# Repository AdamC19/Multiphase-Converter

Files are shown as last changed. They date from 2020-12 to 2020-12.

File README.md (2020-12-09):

# Multiphase Forward Converter
This repo contains the hardware source files for my digitally controlled multiphase isolated 1000W forward
converter. (firmware source code repo is
[here](https://github.com/AdamC19/Multiphase-Converter-FW).) This is a work in progress

## Update December 2020
First prototype has been built up, initial testing is promising! See more [here](http://acordingley.us/multiphase-converter/).

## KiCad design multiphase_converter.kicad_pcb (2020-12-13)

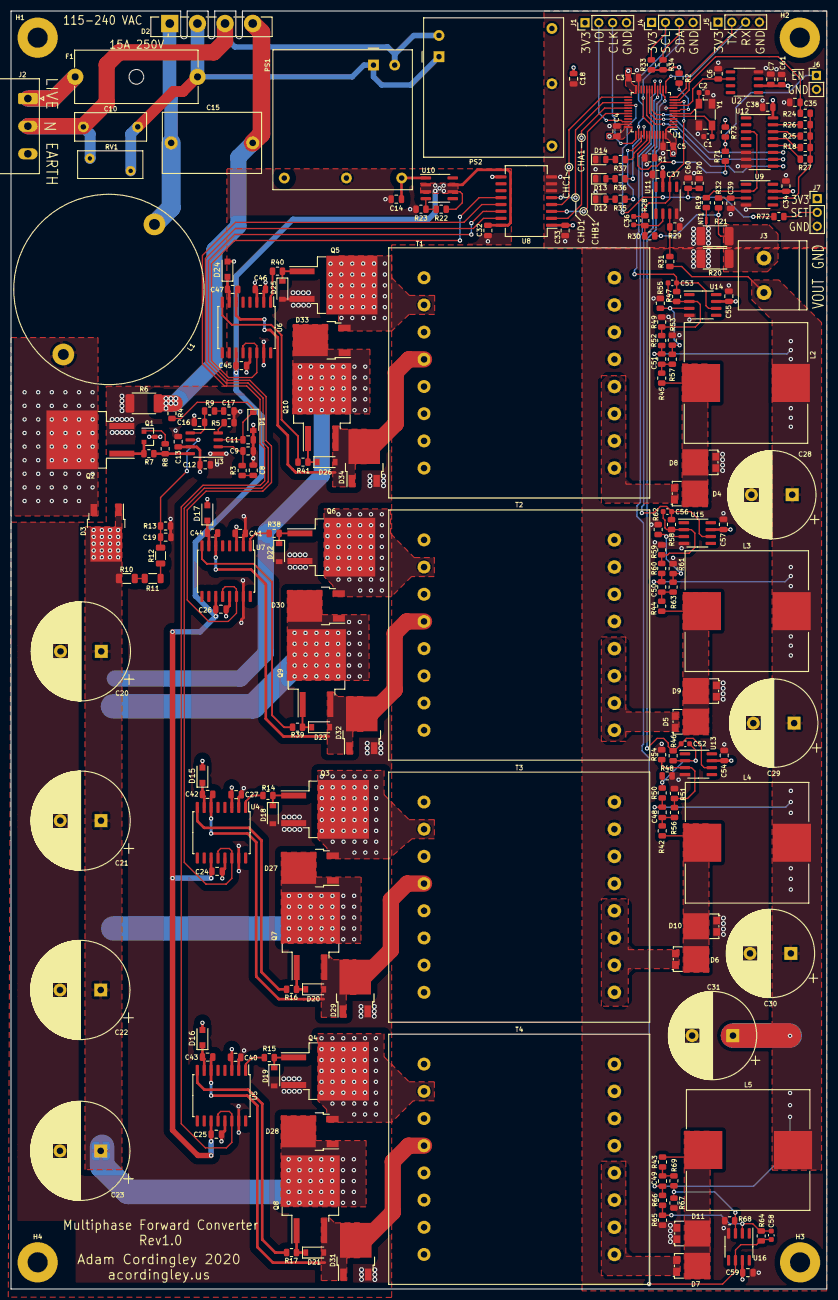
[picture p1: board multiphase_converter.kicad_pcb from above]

Board: 4 copper layers, 150.0 x 235.0 mm, 220 parts (0 on the bottom side), 123 nets.

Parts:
C1, C2: 18p; C_0603_1608Metric
C3, C4, C5, C7, C13, C24, C25, C26, C27, C32, C33, C34, C35, C37, C38, C40, C41, C42, C43, C44, C45, C46, C47, C48, C49, C50, C51, C54, C55, C57, C59, C60: 0.1u; C_0805_2012Metric
C6, C12, C61: 1u; C_0805_2012Metric
C8: DNP; C_0805_2012Metric
C9, C11: 1200p; C_0805_2012Metric
C10: 4700p; C_Rect_L13.0mm_W5.0mm_P10.00mm_FKS3_FKP3_MKS4
C14, C18: 10u; C_0805_2012Metric
C15: R463I347050N0M; C_Rect_L18.0mm_W11.0mm_P15.00mm_FKS3_FKP3
C16: 2.2u; C_0805_2012Metric
C17: 22u; C_0805_2012Metric
C19: 680p; C_0805_2012Metric
C20, C21, C22, C23: 220u; CP_Radial_D18.0mm_P7.50mm
C28, C29, C30, C31: UCS2C221MHD1TN; CP_Radial_D16.0mm_P7.50mm
C36, C52, C53, C56, C58: 6.8p; C_0603_1608Metric
C39: 0.01u; C_0805_2012Metric
D1: 1N4148W; D_SOD-123
D2: GBU2510-G; Diode_Bridge_Vishay_GBU
D3, D27, D28, D29, D30, D31, D32, D33, D34: C3D04060E; TO-252-2
D4, D5, D6, D7, D8, D9, D10, D11: FSV15100V; TO-277A
D12, D13, D14: LED; LED_0805_2012Metric
D15, D16, D17, D24: S1MFL; D_SOD-123F
D18, D19, D20, D21, D22, D23, D25, D26: 15V; D_SOD-123
F1: 0031.8201; Fuseholder_Cylinder-5x20mm_Schurter_0031_8201_Horizontal_Op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
H1, H2, H3, H4: #6; MountingHole_3.7mm_Pad
J1, J4, J5: Conn_01x04_Male; PinHeader_1x04_P2.54mm_Vertical
J2: 1923872; PhoenixContact_MSTBA_2,5_3-G-5,08_1x03_P5.08mm_Horizontal
J3: 1714955; Phoenix_MKDS_5_2-6,35
J6: Conn_01x02_Male; PinHeader_1x02_P2.54mm_Vertical
J7: Conn_01x03_Male; PinHeader_1x03_P2.54mm_Vertical
L1: 120u; Bourns_1140_121K
L2, L3, L4, L5: 74435583300; L_Wuerth_HCI-2212
NT1: Net-Tie_2; NetTie-2_SMD_Pad0.5mm
PS1: RAC05-12SK; Converter_ACDC_RECOM_RAC05-xxSK_THT
PS2: RAC05-3.3SK; Converter_ACDC_RECOM_RAC05-xxSK_THT
Q1: BC807; SOT-23
Q2: IPB60R060P7ATMA1; TO-263-2
Q3, Q4, Q5, Q6, Q7, Q8, Q9, Q10: Q_NMOS_GDS; TO-263-2
R1, R2, R8, R19, R24, R32: 1k; R_0805_2012Metric
R3: DNP; R_0805_2012Metric
R4: 220; R_0805_2012Metric
R5: 13.7k; R_0805_2012Metric
R6: 0.015; R_2512_Power
R7, R14, R15, R16, R17, R38, R39, R40, R41: 3.3; R_0805_2012Metric
R9: 4.7k; R_0805_2012Metric
R10, R11, R12: 330k; R_1206_3216Metric
R13: 14.3k; R_0805_2012Metric
R18: 1.5M; R_0805_2012Metric
R20, R21: 0.003; R_2512_Power
R22: 240; R_0805_2012Metric
R23: 720; R_0805_2012Metric
R25, R30, R31, R50, R52, R56, R57, R60, R63, R66, R69, R70: 200k; R_0805_2012Metric
R26, R71, R72: 100k; R_0805_2012Metric
R27: 50k; R_0805_2012Metric
R28, R29, R48, R49, R51, R53, R59, R61, R65, R67, R73: 10k; R_0805_2012Metric
R33, R34: 2.2k; R_0805_2012Metric
R35, R36, R37: 330; R_0805_2012Metric
R42, R43, R44, R45: 25k; R_0805_2012Metric
R46, R47, R54, R55, R58, R62, R64, R68: 2.4M; R_0805_2012Metric
RV1: MOV-10D391KTR; RV_Disc_D12mm_W5.1mm_P7.5mm
T1, T2, T3, T4: Wurth_760895751
U1: STM32F334C8Tx; LQFP-48_7x7mm_P0.5mm
U2: ADR45xx; SO-8_3.9x4.9mm_P1.27mm
U3: UCC28180; SO-8_3.9x4.9mm_P1.27mm
U4, U5, U6, U7: IR2113S; SOIC-16W_7.5x10.3mm_P1.27mm
U8: ADuM260N; SOIC-16W_7.5x12.8mm_P1.27mm
U9: AD8551; SOIC-8_3.9x4.9mm_P1.27mm
U10: LM317L_SO8; SOIC-8_3.9x4.9mm_P1.27mm
U11, U13, U14, U15, U16: TSV911IDT; SOIC-8_3.9x4.9mm_P1.27mm
U12: 74HC4051; SOIC-16_3.9x9.9mm_P1.27mm
Y1: ABM3B-16.000MHZ-B2-T; Crystal_SMD_Abracon_ABM3B-4Pin_5.0x3.2mm

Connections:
+3V3: C3.2, C4.2, C5.2, C7.1, C18.1, C33.1, C34.1, C37.1, C38.1, C54.1, C55.1, C57.1, C59.1, C61.2, J1.1, J4.1, J5.1, J7.1, PS2.5, R2.1, R33.1, R34.1, R73.1, U1.1, U1.24, U1.36, U1.48, U2.2, U8.1, U9.7, U11.7, U12.16, U13.7, U14.7, U15.7, U16.7
+5VA: C24.1, C25.1, C26.1, C32.1, C45.1, R22.1, U4.11, U5.11, U6.11, U7.11, U8.16, U10.2, U10.3, U10.6, U10.7
+12V: C12.2, C13.2, C14.1, C27.2, C40.2, C41.2, C46.2, D15.2, D16.2, D17.2, D24.2, PS1.5, U3.7, U4.3, U5.3, U6.3, U7.3, U10.1
/Control/ENABLE: R71.2, U1.42
/Control/RX: J5.3, U1.13
/Control/SCL: J4.2, R33.2, U1.38
/Control/SDA: J4.3, R34.2, U1.43
/Control/SWDCLK: J1.3, U1.37
/Control/SWDIO: J1.2, U1.34
/Control/TX: J5.2, U1.12
/Control/VREF: C6.2, U1.9, U2.6
/Control/V_SET: C60.1, R70.2, R72.1, U1.28
/Converter Stage/P1_GATE: U4.12, U4.14, U8.15
/Converter Stage/P1_ISNS: C48.2, R42.1, R56.2
/Converter Stage/P2_GATE: U7.12, U7.14, U8.14
/Converter Stage/P2_ISNS: C50.2, R44.1, R63.2
/Converter Stage/P3_GATE: U5.12, U5.14, U8.13
/Converter Stage/P3_ISNS: C49.2, R43.1, R69.2
/Converter Stage/P4_GATE: U6.12, U6.14, U8.12
/Converter Stage/P4_ISNS: C51.2, R45.1, R57.2
/Converter Stage/T1_HI: C47.1, D26.2, D34.1, D34.2, Q10.3, T1.12, U6.6
/Converter Stage/T2_HI: C44.1, D23.2, D32.1, D32.2, Q9.3, T2.12, U7.6
/Converter Stage/T3_HI: C42.1, D20.2, D29.1, D29.2, Q7.3, T3.12, U4.6
/Converter Stage/T3_LO: D27.3, Q3.2, T3.10
/Converter Stage/T4_HI: C43.1, D21.2, D31.1, D31.2, Q8.3, T4.12, U5.6
/Converter Stage/VOUT_LO: J3.2, R20.1, R21.1, R30.2, R32.2
/Mains Power Input/LINE_IN: F1.2, J2.1
GNDA: C8.1, C9.1, C11.1, C12.1, C13.1, C14.2, C16.1, C17.1, C19.2, C20.2, C21.2, C22.2, C23.2, C24.2, C25.2, C26.2, C27.1, C32.2, C40.1, C41.1, C45.2, C46.1, D1.2, D18.2, D19.2, D22.2, D25.2, D29.3, D31.3, D32.3, D34.3, PS1.4, Q1.3, Q2.3, Q3.3, Q4.3, Q5.3, Q6.3, R5.1, R6.1, R13.1, R23.2, U3.1, U4.2, U4.13, U4.15, U5.2, U5.13, U5.15, U6.2, U6.13, U6.15, U7.2, U7.13, U7.15, U8.9
GNDD: C1.2, C2.2, C3.1, C4.1, C5.1, C6.1, C7.2, C18.2, C28.2, C29.2, C30.2, C31.2, C33.2, C34.2, C35.1, C37.2, C38.2, C39.1, C54.2, C55.2, C57.2, C59.2, C60.2, C61.1, D8.1, D8.2, D9.1, D9.2, D10.1, D10.2, D11.1, D11.2, D12.1, D13.1, D14.1, J1.4, J4.4, J5.4, J6.2, J7.3, NT1.2, PS2.4, R1.2, R20.2, R21.2, R29.1, R48.2, R49.2, R51.2, R53.2, R54.2, R55.2, R59.2, R61.2, R62.2, R65.2, R67.2, R68.2, R70.1, T1.5, T1.6, T1.7, T1.8, T2.5, T2.6, T2.7, T2.8, T3.5, T3.6, T3.7, T3.8, T4.5, T4.6, T4.7, T4.8, U1.8, U1.23, U1.35, U1.47, U2.4, U8.6, U8.7, U8.8, U9.4, U11.4, U12.6, U12.7, U12.8, U13.4, U14.4, U15.4, U16.4, Y1.2, Y1.4
HRTIM_CHA1: U1.29, U8.2
HRTIM_CHB1: U1.31, U8.3
HRTIM_CHC1: U1.25, U8.4
HRTIM_CHD1: U1.27, U8.5
IMUX_0: U1.18, U12.11
IMUX_1: U1.19, U12.10
IMUX_2: U1.20, U12.9
I_FB: C35.2, R24.1, U1.11
LINE: C10.1, D2.2, F1.1, PS1.1, PS2.1, RV1.1
NEUT: C10.2, D2.3, J2.2, PS1.2, PS2.2, RV1.2
unnamed: C1.1, U1.5, Y1.3
unnamed: C2.1, U1.6, Y1.1
unnamed: C8.2, R3.1
unnamed: C9.2, R3.2, U3.2
unnamed: C11.2, D1.1, R4.1, U3.3
unnamed: C15.1, D2.1, L1.1
unnamed: C15.2, D2.4, R4.2, R6.2
unnamed: C16.2, R9.1, U3.5
unnamed: C17.2, R9.2
unnamed: C19.1, R12.1, R13.2, U3.6
unnamed: C36.2, R28.1, R30.1, U11.2
unnamed: C39.2, R32.1, U9.3
unnamed: C42.2, D15.1, U4.7
unnamed: C43.2, D16.1, U5.7
unnamed: C44.2, D17.1, U7.7
unnamed: C47.2, D24.1, U6.7
unnamed: C52.2, R46.1, R48.1, R50.1, U13.2
unnamed: C53.2, R47.1, R49.1, R52.1, U14.2
unnamed: C56.2, R58.1, R59.1, R60.1, U15.2
unnamed: C58.2, R64.1, R65.1, R66.1, U16.2
unnamed: D3.3, L1.2, Q2.2
unnamed: D4.1, D4.2, T1.1, T1.2, T1.3, T1.4
unnamed: D4.3, D8.3, L2.1, R45.2
unnamed: D5.1, D5.2, T2.1, T2.2, T2.3, T2.4
unnamed: D5.3, D9.3, L3.1, R44.2
unnamed: D6.1, D6.2, T3.1, T3.2, T3.3, T3.4
unnamed: D7.1, D7.2, T4.1, T4.2, T4.3, T4.4
unnamed: D6.3, D10.3, L4.1, R42.2
unnamed: D7.3, D11.3, L5.1, R43.2
unnamed: D12.2, R35.2
unnamed: D13.2, R36.2
unnamed: D14.2, R37.2
unnamed: D18.1, Q3.1, R14.2
unnamed: D19.1, Q4.1, R15.2
unnamed: D20.1, Q7.1, R16.2
unnamed: D21.1, Q8.1, R17.2
unnamed: D22.1, Q6.1, R38.2
unnamed: D23.1, Q9.1, R39.2
unnamed: D25.1, Q5.1, R40.2
unnamed: D26.1, Q10.1, R41.2
unnamed: D28.3, Q4.2, T4.10
unnamed: D30.3, Q6.2, T2.10
unnamed: D33.3, Q5.2, T1.10
unnamed: J6.1, R71.1, R73.2
unnamed: J7.2, R72.2
unnamed: NT1.1, R19.2
unnamed: Q1.1, R8.1
unnamed: Q1.2, Q2.1, R7.1
unnamed: R1.1, U1.44
unnamed: R2.2, U1.7
unnamed: R5.2, U3.4
unnamed: R7.2, R8.2, U3.8
unnamed: R10.1, R11.2
unnamed: R11.1, R12.2
unnamed: R14.1, U4.1
unnamed: R15.1, U5.1
unnamed: R16.1, U4.8
unnamed: R17.1, U5.8
unnamed: R18.1, R24.2, R25.1, R26.1, R27.1, U9.6
unnamed: R18.2, U12.13
unnamed: R19.1, U9.2, U12.3
unnamed: R22.2, R23.1, U10.4
unnamed: R25.2, U12.14
unnamed: R26.2, U12.15
unnamed: R27.2, U12.12
unnamed: R29.2, R31.1, U11.3
unnamed: R35.1, U1.39
unnamed: R36.1, U1.40
unnamed: R37.1, U1.41
unnamed: R38.1, U7.1
unnamed: R39.1, U7.8
unnamed: R40.1, U6.1
unnamed: R41.1, U6.8
unnamed: R51.1, R54.1, R56.1, U13.3
unnamed: R53.1, R55.1, R57.1, U14.3
unnamed: R61.1, R62.1, R63.1, U15.3
unnamed: R67.1, R68.1, R69.1, U16.3
P1_IFB: C52.1, R46.2, U1.14, U13.6
P2_IFB: C56.1, R58.2, U1.15, U15.6
P3_IFB: C58.1, R64.2, U1.16, U16.6
P4_IFB: C53.1, R47.2, U1.17, U14.6
VBUS: C20.1, C21.1, C22.1, C23.1, D3.1, D3.2, D27.1, D27.2, D28.1, D28.2, D30.1, D30.2, D33.1, D33.2, Q7.2, Q8.2, Q9.2, Q10.2, R10.2
VCC: C28.1, C29.1, C30.1, C31.1, C48.1, C49.1, C50.1, C51.1, J3.1, L2.2, L3.2, L4.2, L5.2, R31.2, R50.2, R52.2, R60.2, R66.2
V_FB: C36.1, R28.2, U1.10, U11.6

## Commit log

2020-11-15 All work to date
    [control.sch, converter.sch, mains_power_in.sch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]
2020-11-16 Updates to PCB to get ready for manufacture
    [multiphase_converter.kicad_pcb]
2020-11-18 Final design sent out for fabrication
    [control.sch, converter.sch, mains_power_in.sch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]
2020-12-13 Annotations to schematics, fix bootstrap diodes
    [control.sch, converter.sch, mains_power_in.sch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]
